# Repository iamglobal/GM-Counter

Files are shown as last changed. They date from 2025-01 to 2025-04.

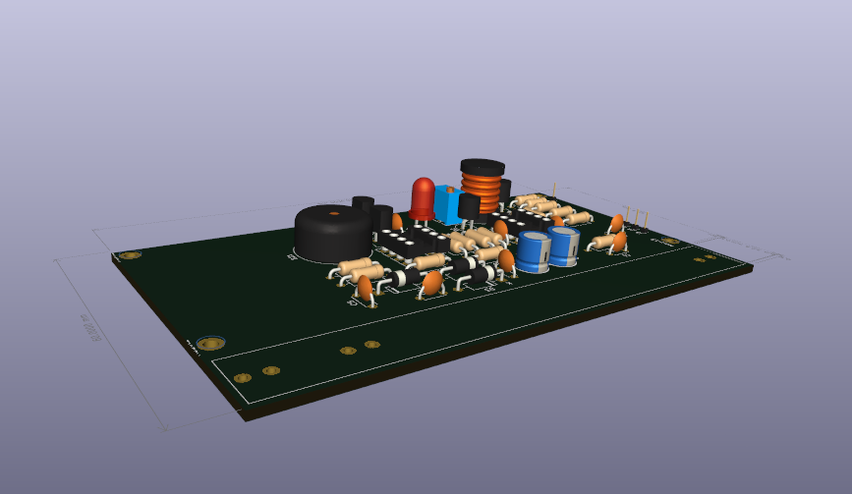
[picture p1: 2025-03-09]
-DOCUMENTATION-/extras/photos of PCB/plosnakv2_3D.png

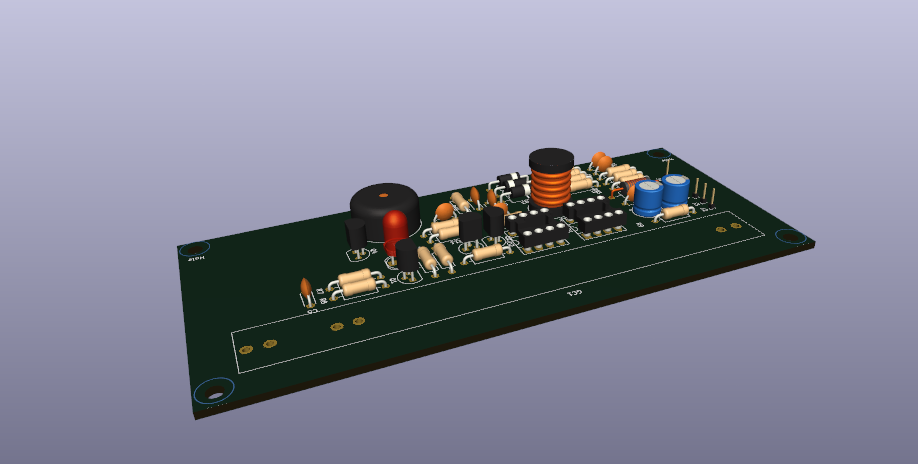
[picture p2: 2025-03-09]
-DOCUMENTATION-/extras/photos of PCB/plosnakv1_3D.png

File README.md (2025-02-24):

# GM-Counter
This is my first project of my own. GM-Counter is a long-term pre-graduation project for SPŠ na Proseku for the year 2025.

## Sources: 
- [SBM-20 data](https://www.gstube.com/data/2398/)
- [GM tubes comparison](https://iot-devices.com.ua/en/comparison-of-geiger-muller-tubes-sbm20-j305-and-lnd712/)
- [GM counter project](https://hackaday.io/project/183103-ggreg20v3-ionizing-radiation-detector)
- [Twin tube GM counter project](https://www.giangrandi.org/electronics/twin-tube-geiger/twin-tube-geiger.shtml)
- [GM Tubes info - CPM to uSv etc.](https://sites.google.com/site/diygeigercounter/technical/gm-tubes-supported)

## Components: 
- [GM kit with M4011 tube (first testing etc.)](https://www.aliexpress.com/item/1005005983829775.html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)
- [SBM-20 GM tube](https://www.ebay.com/itm/280865770387)
- [GM TUBE HOLDER PART](https://cz.mouser.com/ProductDetail/Littelfuse/01020071Z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)
- Arduino Nano
- 0,96 inch OLED display

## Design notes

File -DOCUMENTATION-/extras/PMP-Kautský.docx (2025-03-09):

# Název: Digitální dozimetr

## Popis

Chci vytvořit zařízení, které dokáže měřit ionizující záření. Při naměření radiace „zabzučí“ bzučák a zároveň se rozsvítí LED. Tento pulz se téže dostane do Arduina, do digitálního vstupu (stačí tyto impulzy číst jako 1 a 0). Pro přesnější informaci bude použit displej, kde se bude ukazovat přibližná hodnota radiace v okolí (CPS, CPM, uSv/h, mR/h, nebo jiné). Později mohou být přidány další funkce právě na tento displej (např. Radiace za čas). Je zde i možnost přidání tlačítek k lepšímu ovládání Arduina, např. pro výměnu trubek (každá má jiný převod).

## Řešení

Základem je využít Geigerovu trubici, Arduino a libovolný displej. Geigerova trubice slouží pro měření radiačního záření. Arduino a displej poslouží pro zpracování dat z měření, výpočty a jasné vyhodnocení na zmíněný displej. Celý měřič bude uložen do kompaktního boxu, který nejspíše bude tištěn pomocí 3D tisku. Pro testy trubic a inspiraci jsem si pořídil samotný KIT, který mi bude velkou pomocí. Pro ověření funkčnosti samotného obvodu mám jako zdroj radiace vybrané wolframové elektrody s obsahem Thoria, na kterých zvýšenou radiaci jednoduše naměříme.

## Odkazy

## https://www.instructables.com/Homemade-Geiger-Counter/

https://www.instructables.com/DIY-Arduino-Geiger-Counter/
https://dspace.cvut.cz/bitstream/handle/10467/76812/F8-BP-2018-Kuchar-Libor-thesis.pdf?sequence=-1&isAllowed=y

## Obrázky

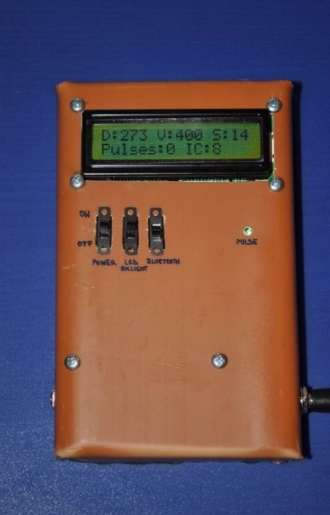
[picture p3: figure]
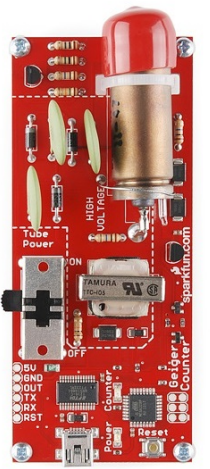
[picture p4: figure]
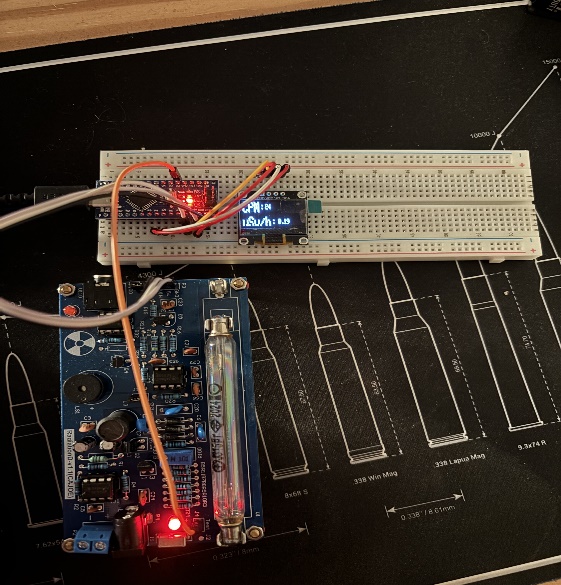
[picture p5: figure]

Příprava dlouhodobé maturitní práce Kautský 3.EA školní rok 2024/2025

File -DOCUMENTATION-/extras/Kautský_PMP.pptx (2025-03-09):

## Digitální dozimetr

PMP 2024/2025

Kautský Ondřej 3.EA

## Úvod

- Výběr projektu: Jako svůj projekt jsem si vybral digitální dozimetr, který slouží k detekci ionizujícího záření. Hlavním senzorem je Geigerova-Müllerova trubice, která reaguje na radioaktivní částice. Celý systém je však řízen vývojovou deskou Arduino. Tento projekt jsem si vybral, protože mě zajímala radiace a její měření.
- Mezi hlavní funkce patří: Vizuální indikace detekovaného záření – pomocí LED Akustická signalizace – zvukový výstup přes buzzer Srozumitelnější data – přepočet impulzů na µSv/h a zobrazení na displeji

## Cíle projektu

Elektrická část – Vyvinout efektivní a funkční PCB, přičemž jsem vycházel z existujícího návrhu a přizpůsobil ho potřebám projektu tím, že jsem odstranil nepotřebné části a jiné zase upravil.
Mechanická část – Navrhnout kompaktní, ale robustní kryt, který bude minimálně ovlivňovat měření.
Programová část – Vytvořit program pro zobrazování vypočtených dat na displeji v zásadě na trubce. Rád bych zde přidal funkci, kde lze typ GM trubky vybrat.

## Schéma obvodu

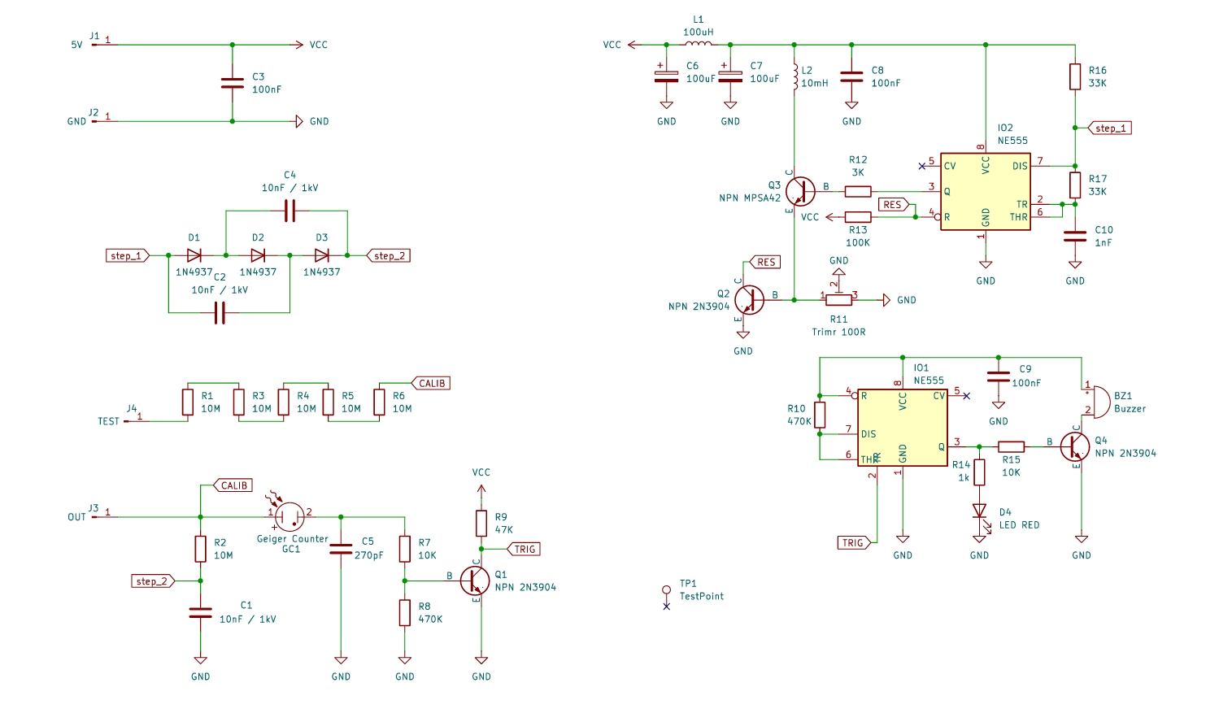
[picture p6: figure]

## Napěťová část (5V -> +-380V)

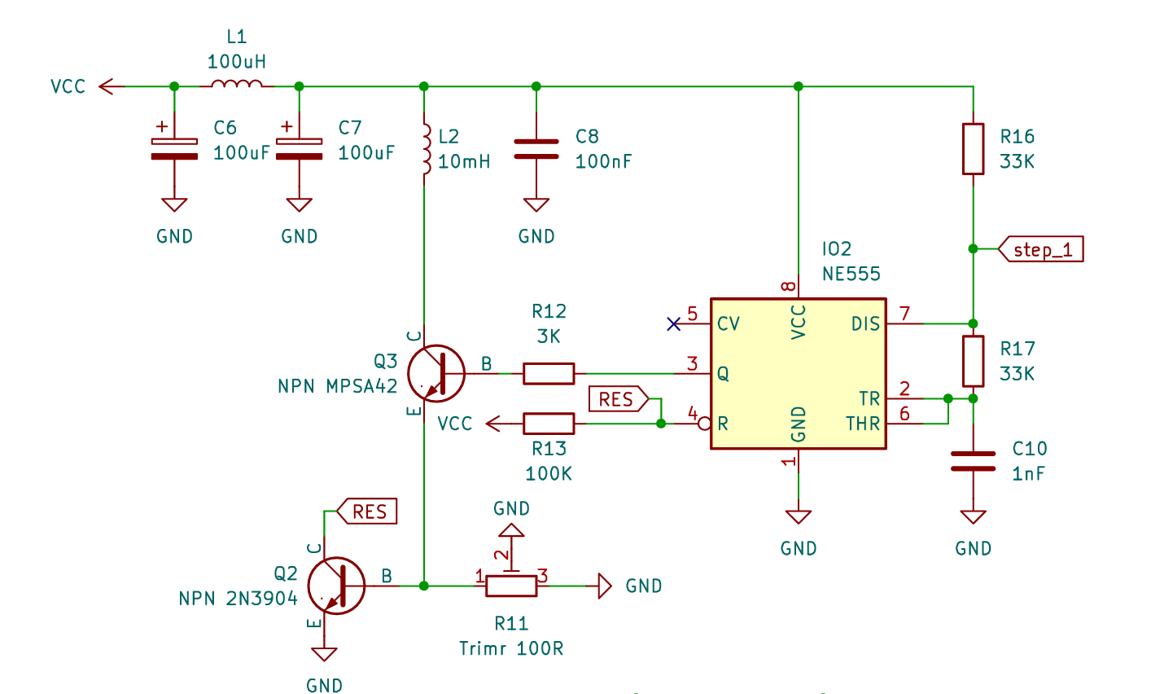
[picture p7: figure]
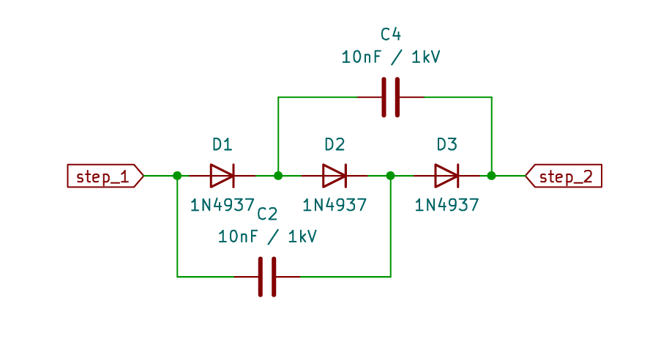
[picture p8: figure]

## Část s vizuální a akustickou signalizací

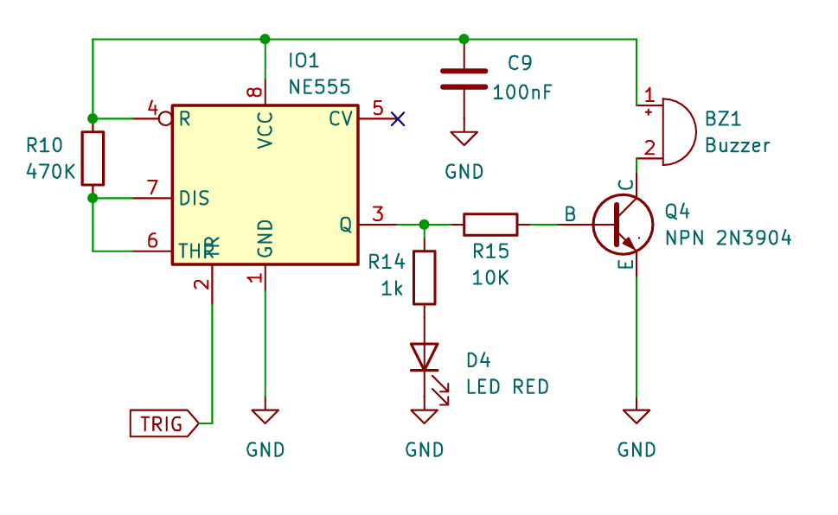
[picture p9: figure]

## Část s GM trubicí

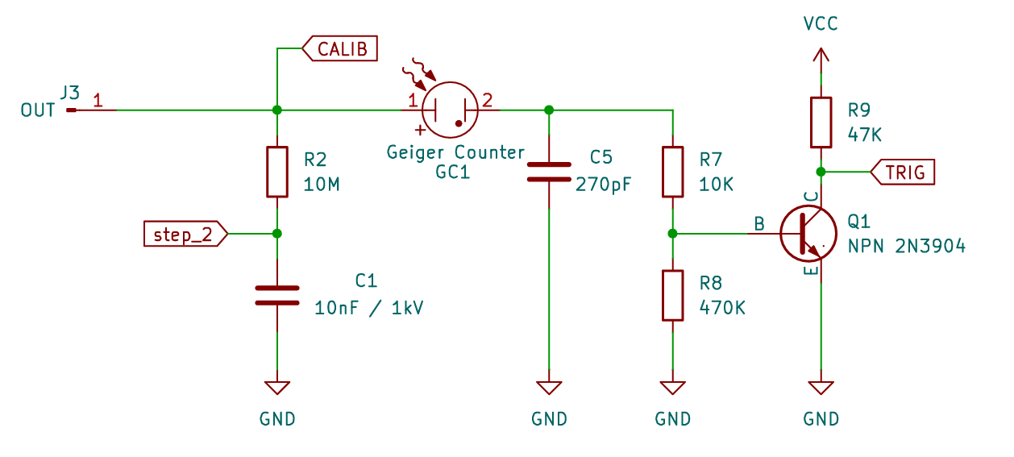
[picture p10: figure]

## PCB v1 (návrh)

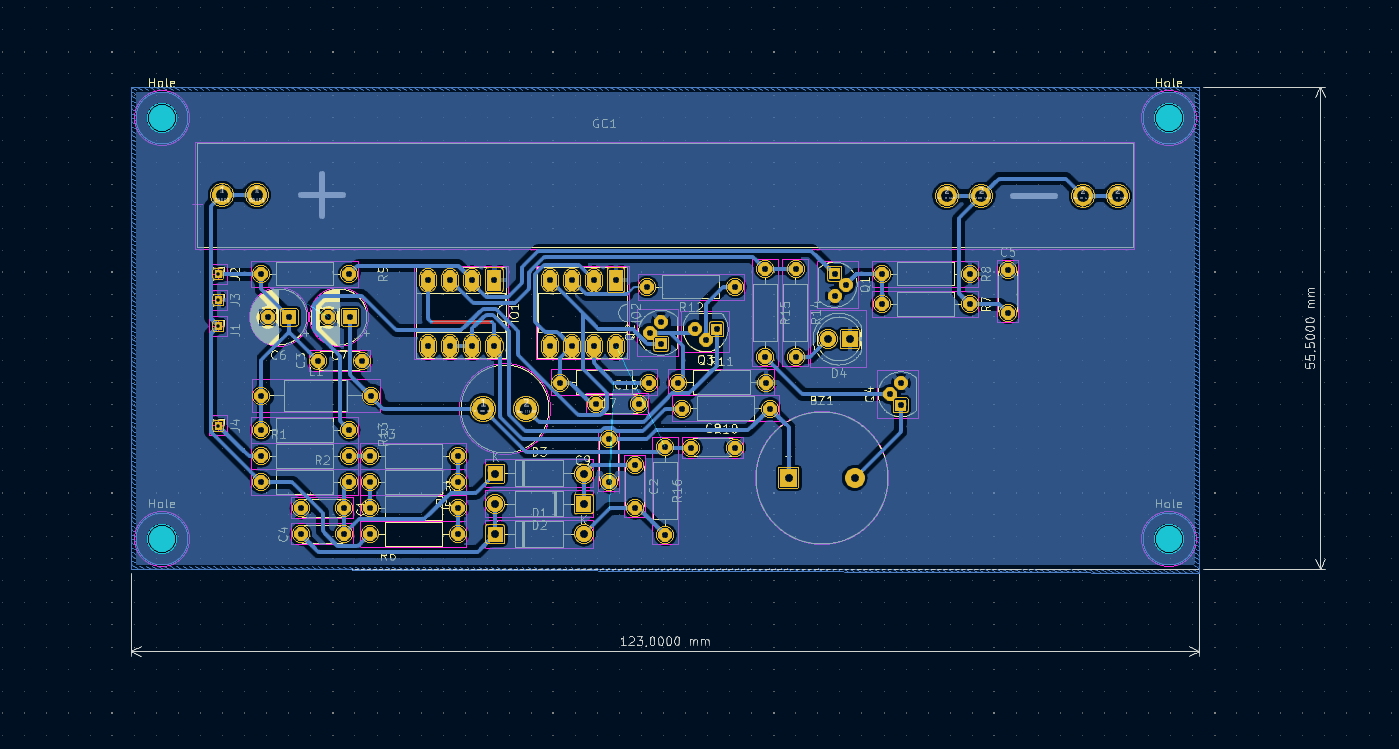
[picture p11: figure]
Obsah obrázku text, snímek obrazovky, mapa, Multimediální software Obsah vygenerovaný umělou inteligencí může být nesprávný.

- Úzké cesty
- Špatné rozvržení
- Relativně velké

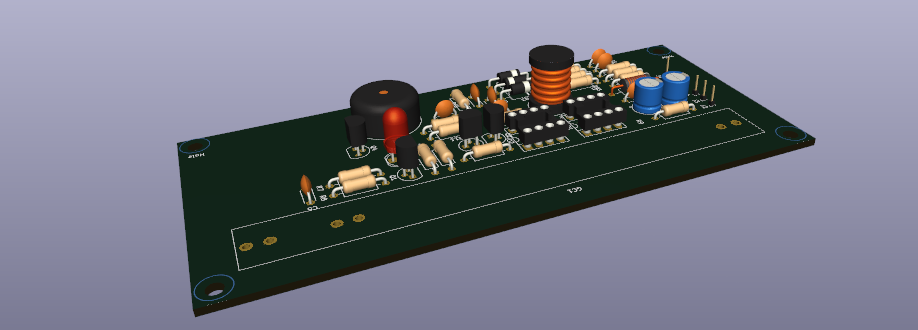
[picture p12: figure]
Obsah obrázku snímek obrazovky, obvod Obsah vygenerovaný umělou inteligencí může být nesprávný.

## PCB v2 (první fyzické)

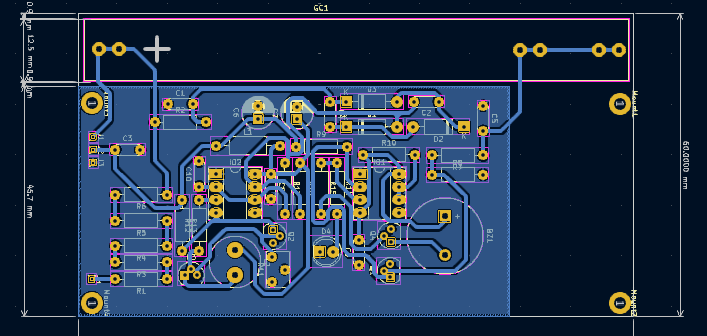
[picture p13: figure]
Obsah obrázku text, mapa, snímek obrazovky, diagram Obsah vygenerovaný umělou inteligencí může být nesprávný.

- Cesty 0,7mm
- Kompaktnější rozměry
- Velké nevyužité místo

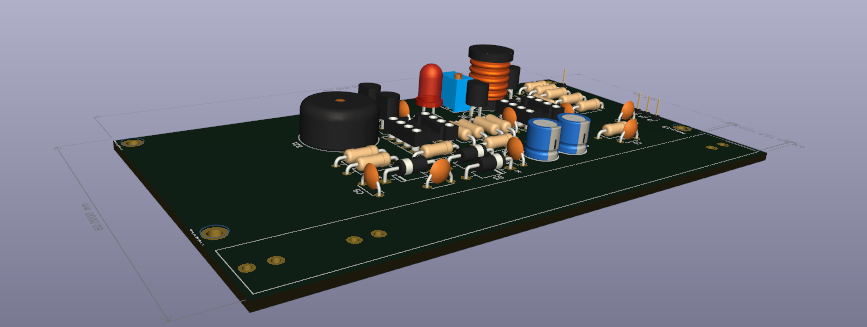
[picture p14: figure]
Obsah obrázku hračka Obsah vygenerovaný umělou inteligencí může být nesprávný.

## PCB v2 – Návrh kompaktního designu

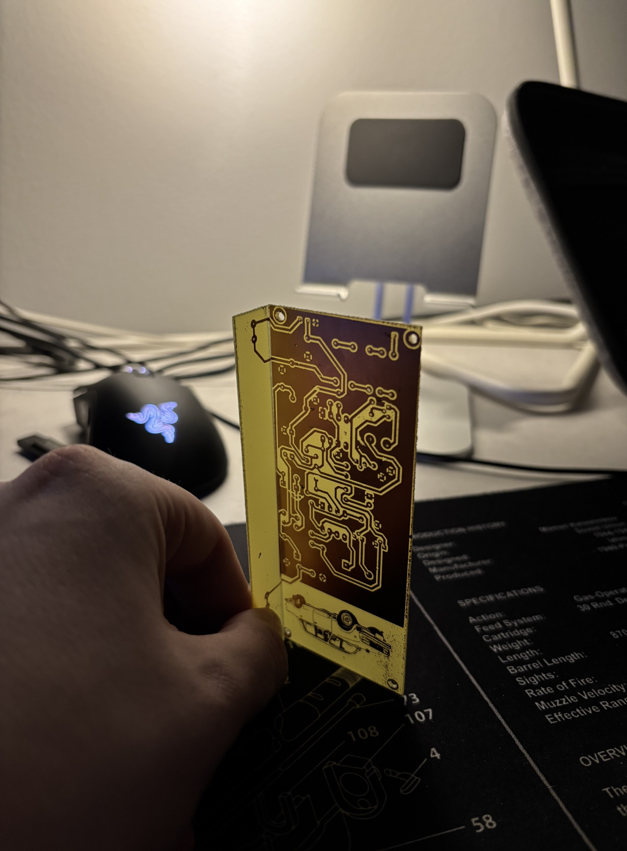
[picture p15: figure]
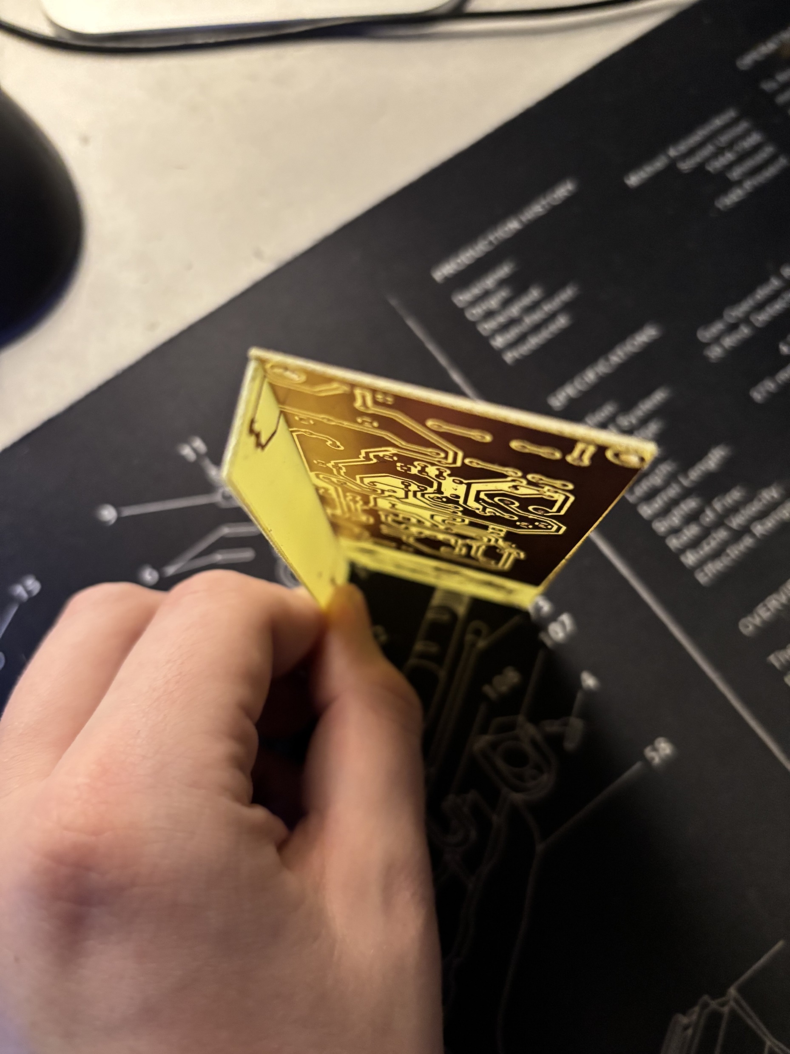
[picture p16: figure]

- Aktuální myšlenka je udělat kompaktní design s jednouchou výměnou GM trubic.
- Tímto designem získám i spoustu místa k umístění baterie pod PCB.
- Nevyužitý prostor na PCB by byl využit pro umístění Arduina a displeje.

První kreslený návrh

## PCB v2 – Fyzická podoba

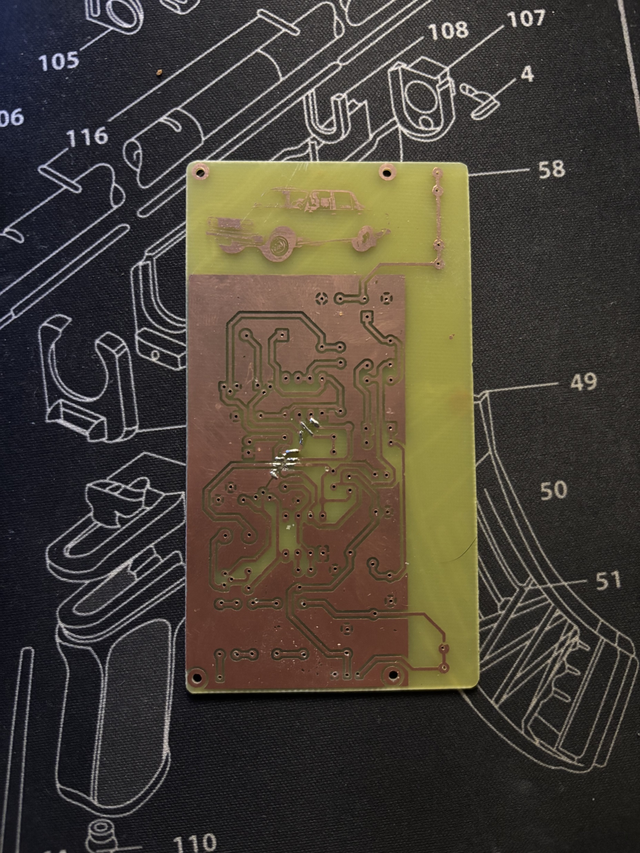
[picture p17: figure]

- K návrhu PCB v2 byly zatím vytvořené 2 kusy. Bohužel se ani jeden nepovedl dostatečně, aby mohl být užit pro první vlastní prototyp. Došlo zde k chybám při leptání (přerušení cest, špatné díry apod.)
- Součástky mám všechny, krom jedné, připravené a pouze musím vytvořit dobré a použitelné DPS.
- U designu s zakřivením do 90° musím vyřešit pevnost a samotný kontakt. Nyní zvažuji že na druhý prototyp bych použil konektory.

## PCB v2 Návrh prototypu krabičky

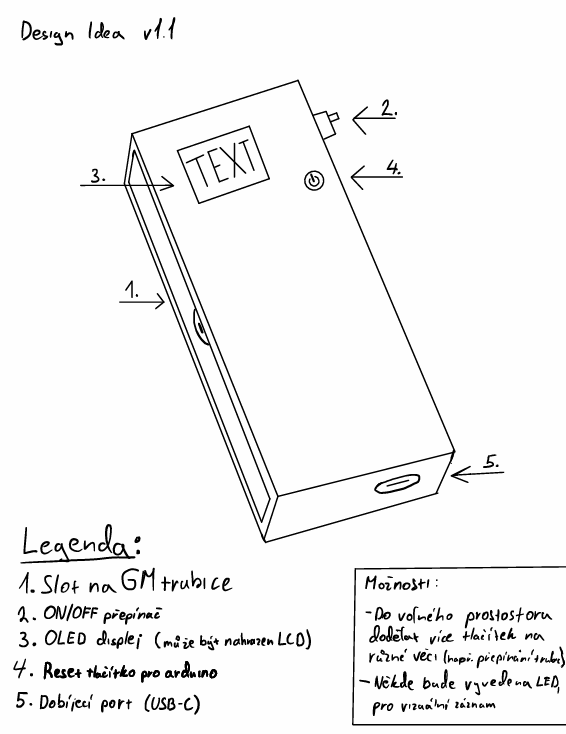
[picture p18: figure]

- Systém otevíracího slotu pro výměnu GM trubic
- Baterie pod DPS
- Velké nevyužité místo (prozatím)

## Cíle do konce dubna

- Dokončit a vytvořit funkční PCB v2
- Vyřešit zbytek programové části (alespoň pro PCB v2)
- Vytisknout, či jinak vytvořit krabičku
- Vyřešit pevnost u designu 90° ohybu
- Zprovoznit zapojení na baterii a její dobíjení

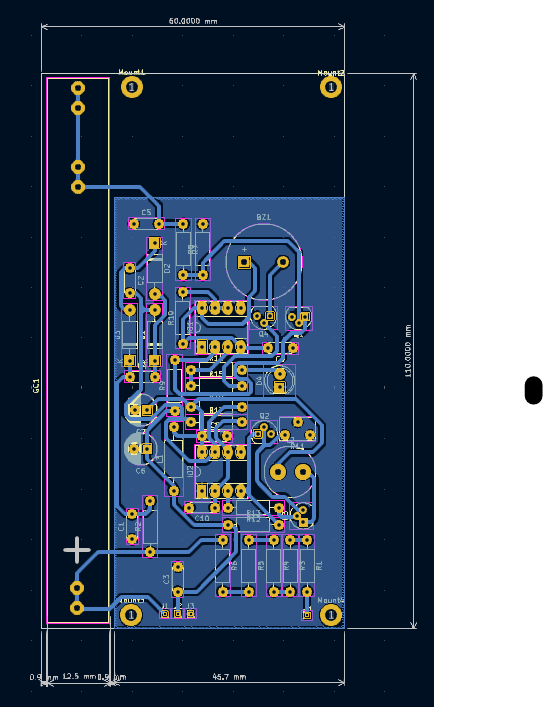
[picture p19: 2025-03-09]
-DOCUMENTATION-/extras/photos of PCB/plosnakv2.png

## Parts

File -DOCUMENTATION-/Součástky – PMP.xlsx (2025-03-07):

 | soucastky na V1 - 1 pokus. Vzit aspon 3x times.
 | Součástka | Počet | URL / KOD | cena
1. | Buzzer | 1ks |  |  | knop
2. | C 10n/1kV | 3ks | CC1K-10N | GM | mam
3. | C 100nF | 5ks | JFH-100N |  | mam
4. | C 270pF | 1ks | CC-271/500 |  | mam
5. | C 1nF | 1ks | CC-1N | GM | mam
6. | D 1N4937 | 3ks | 1N4937-DC |  | mam
7. | LED | 1ks | LTL-4221N |  | mam
8. | NE555 | 2ks | NE555P |  | mam
9. | pin header lista | 1ks | ZL201-40G | GM | mam
10. | L1 100uH R like | 1ks | DLA100-N |  | mam
11. | L2 10mH C like | 1ks | COIL1010-10 |  | mam
12. | NPN 3904 | 3ks | 2N3904-DIO |  | mam
13. | NPN MPSA42 | 1ks | MPSA42-DIO |  | mam
14. | R 10M | 7ks | 1/4W1.0M |  | mam
15. | R 470K | 2ks | 1/4W470K | GM | mam
16. | R 47K | 1Ks | 1/4W47K | GM | mam
17. | R 100K | 1ks | 1/4W100K | GM | mam
18. | R 3K nebo něco close | 2ks | 1/4W3.3K | GM | mam
19. | R 10K | 2ks | 1/4W10K | GM | mam
20. | R 33K | 2ks | MF0207FTE-33K | GM | mam | 2x
21. | TRIMR 100R | 1ks | T910Y-100R
22. | pad na N555 | 2ks | ICVT-8P |  | mam | 2x
23. | drzak na pojistky | 3ks | 01000056Z |  | mam
24. | R 1K | 1ks | 1/4W1.0K | GM | mam
25.
26.
27.
28.
29.
30.

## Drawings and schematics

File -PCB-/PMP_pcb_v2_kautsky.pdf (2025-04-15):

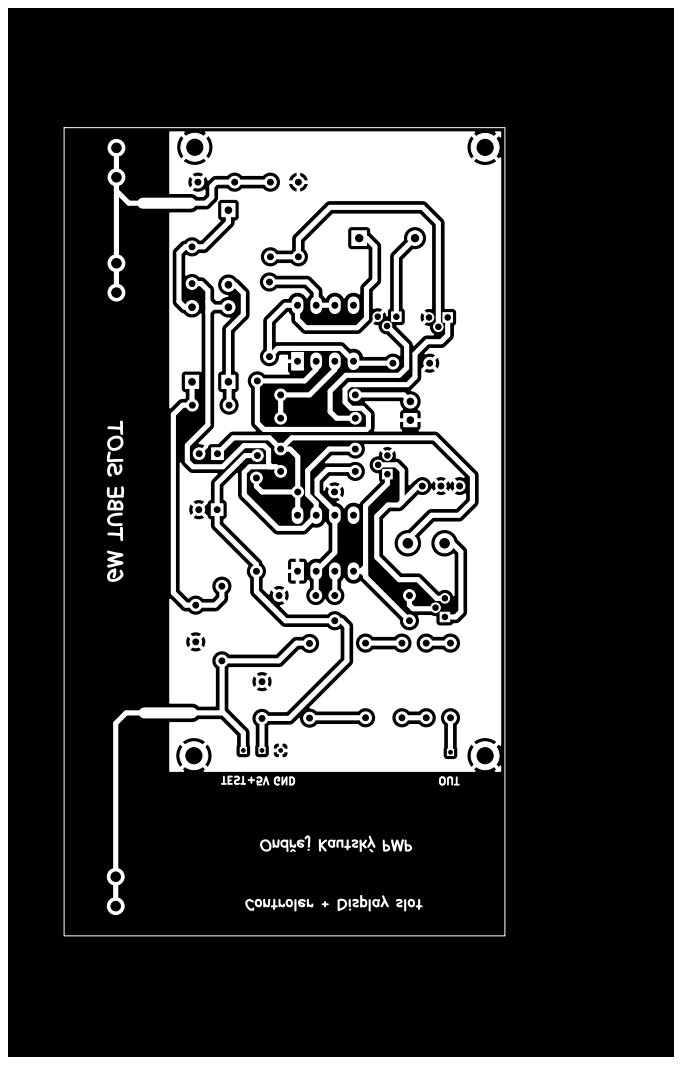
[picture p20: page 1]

+5V GND GM TUBE SLOT

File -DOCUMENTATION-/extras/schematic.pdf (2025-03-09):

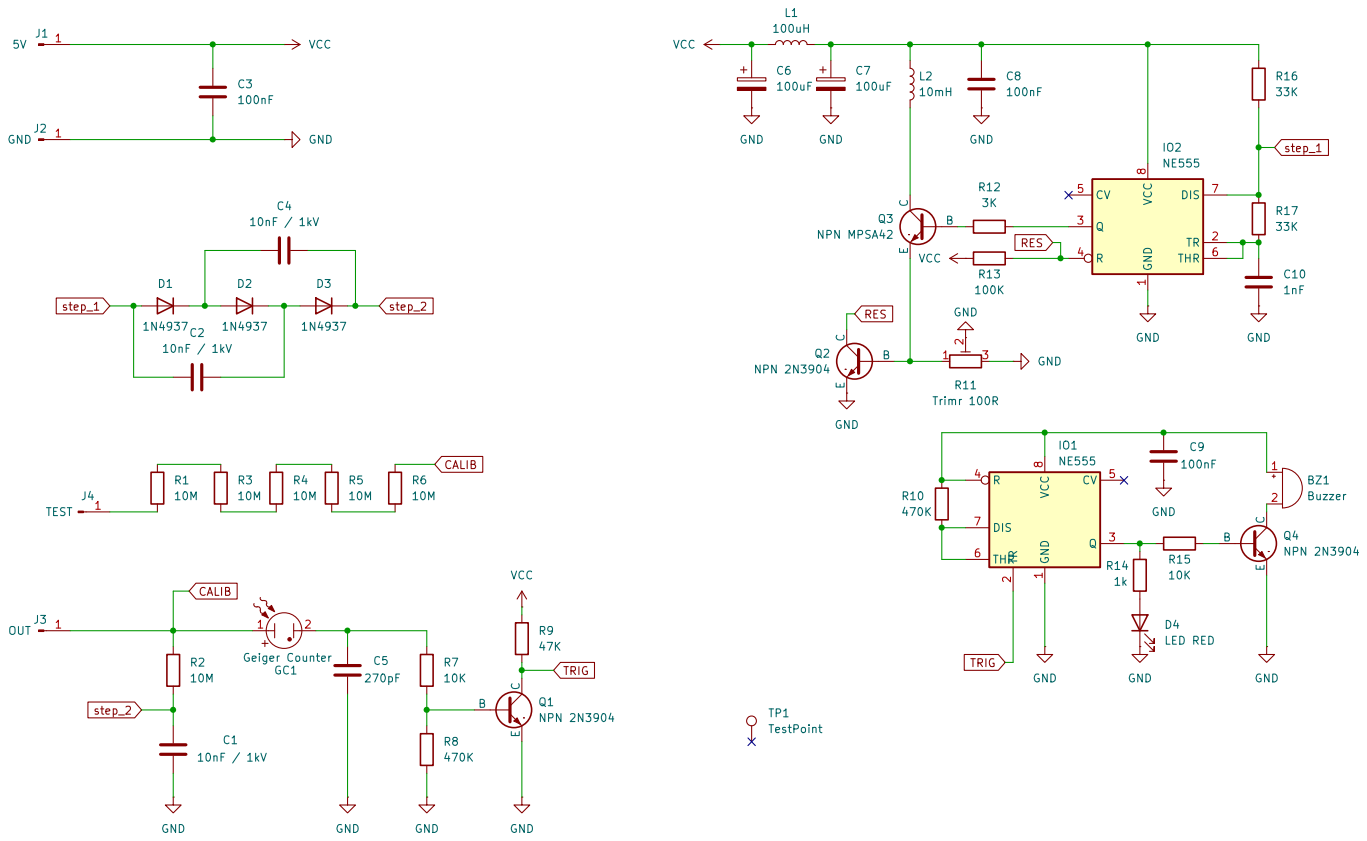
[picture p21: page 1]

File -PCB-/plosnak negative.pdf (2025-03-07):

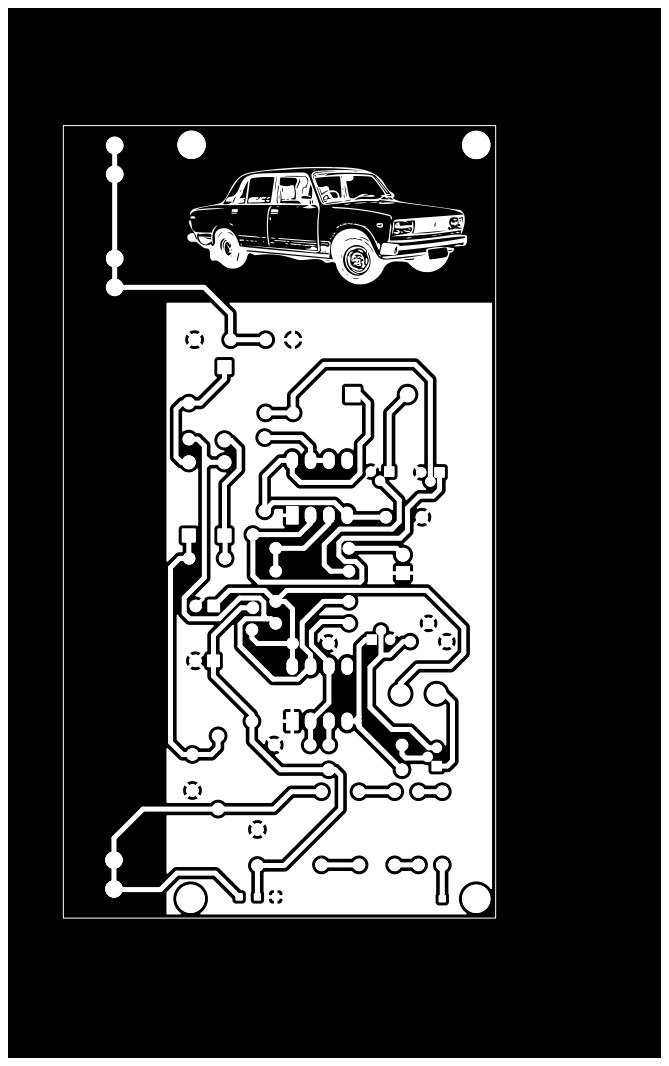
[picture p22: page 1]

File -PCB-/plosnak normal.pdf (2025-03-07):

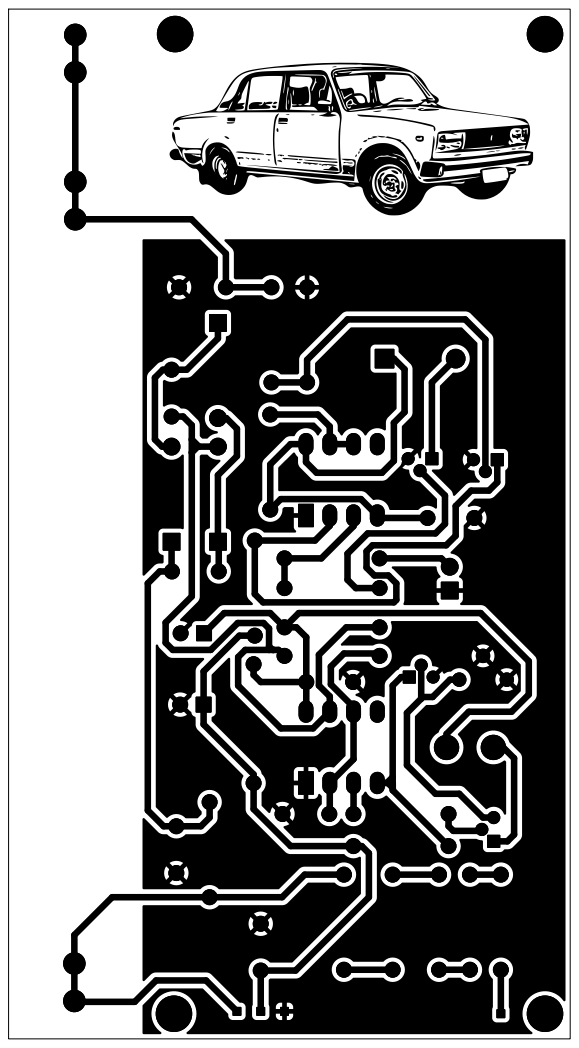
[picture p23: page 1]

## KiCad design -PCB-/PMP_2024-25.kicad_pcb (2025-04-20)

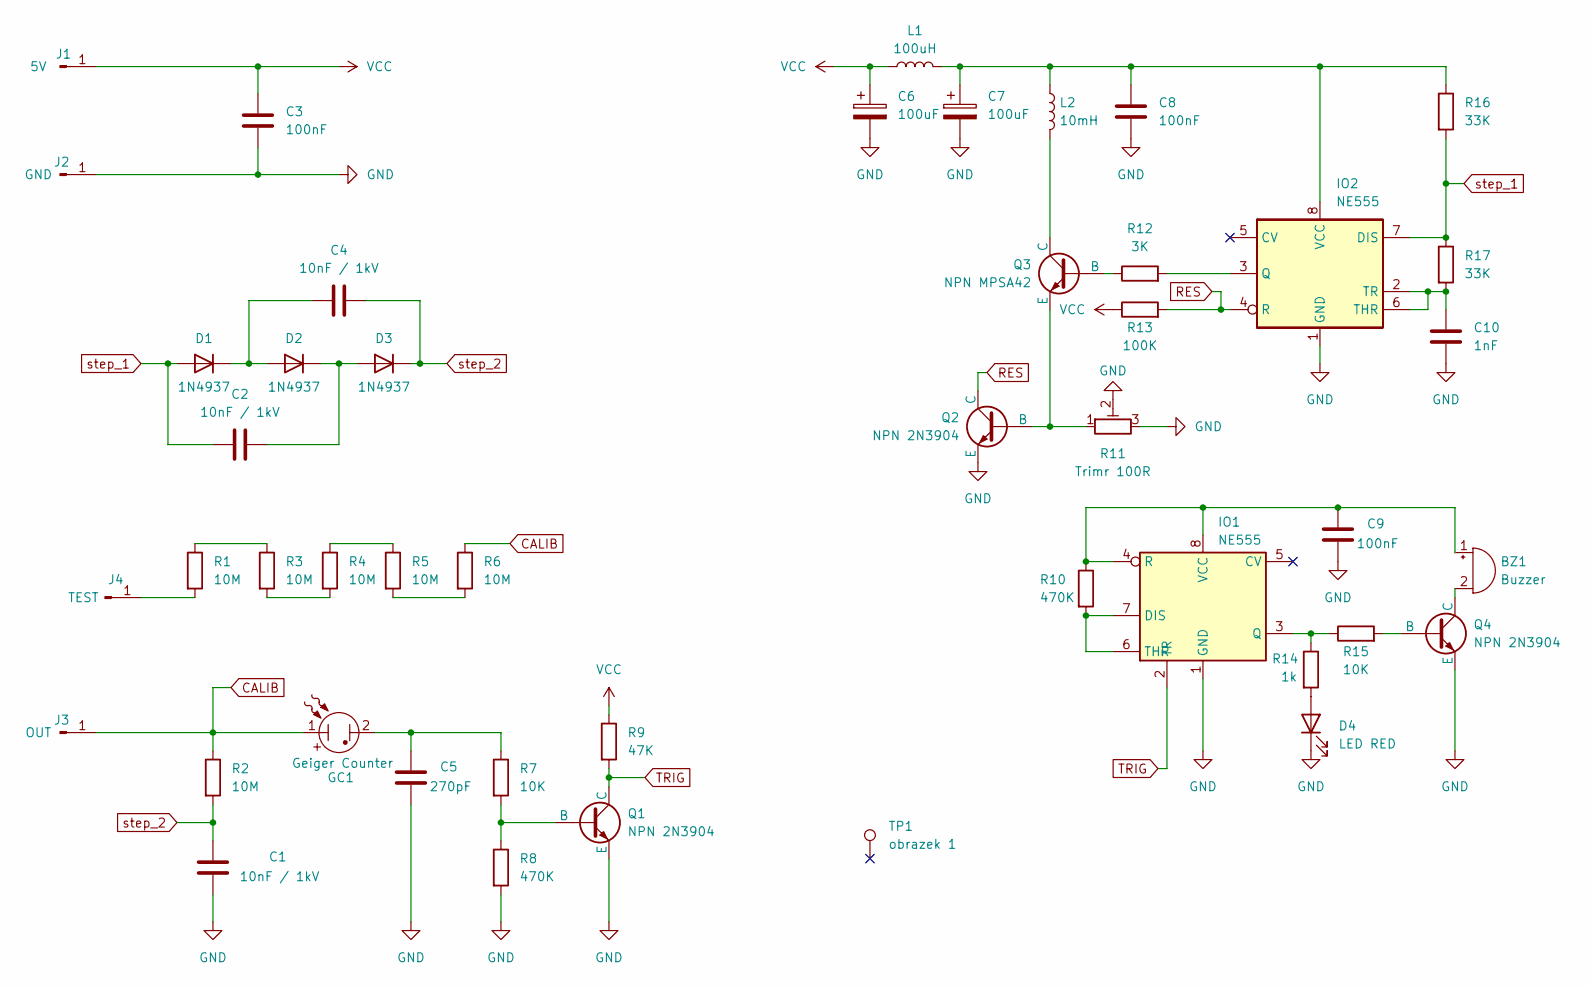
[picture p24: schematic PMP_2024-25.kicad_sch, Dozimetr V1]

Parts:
BZ1: Buzzer; Buzzer_15x7.5RM7.6
C1, C2, C4: 10nF / 1kV; C_Disc_D4.3mm_W1.9mm_P5.00mm
C3, C8, C9: 100nF; C_Disc_D4.3mm_W1.9mm_P5.00mm
C5: 270pF; C_Disc_D4.3mm_W1.9mm_P5.00mm
C6, C7: 100uF; CP_Radial_D6.3mm_P2.50mm
C10: 1nF; C_Disc_D4.3mm_W1.9mm_P5.00mm
D1, D2, D3: 1N4937; D_A-405_P10.16mm_Horizontal
D4: LED RED; LED_D5.0mm
GC1: Geiger Counter; GeigerTube Holder v3 (final)
IO1, IO2: NE555; DIP-8_W7.62mm_Socket_LongPads
J1: 5V; PinHeader_1x01_P1.00mm_Vertical
J2: GND; PinHeader_1x01_P1.00mm_Vertical
J3: OUT; PinHeader_1x01_P1.00mm_Vertical
J4: TEST; PinHeader_1x01_P1.00mm_Vertical
L1: 100uH; L_Axial_L7.0mm_D3.3mm_P12.70mm_Horizontal_Fastron_MICC
L2: 10mH; L_Radial_D10.0mm_P5.00mm_Fastron_07M
Q1, Q2, Q4: NPN 2N3904; TO-92
Q3: NPN MPSA42; TO-92
R1, R2, R3, R4, R5, R6: 10M; R_Axial_DIN0207_L6.3mm_D2.5mm_P10.16mm_Horizontal
R7, R15: 10K; R_Axial_DIN0207_L6.3mm_D2.5mm_P10.16mm_Horizontal
R8, R10: 470K; R_Axial_DIN0207_L6.3mm_D2.5mm_P10.16mm_Horizontal
R9: 47K; R_Axial_DIN0207_L6.3mm_D2.5mm_P10.16mm_Horizontal
R11: Trimr 100R; Potentiometer_Bourns_3296W_Vertical
R12: 3K; R_Axial_DIN0207_L6.3mm_D2.5mm_P10.16mm_Horizontal
R13: 100K; R_Axial_DIN0207_L6.3mm_D2.5mm_P10.16mm_Horizontal
R14: 1k; R_Axial_DIN0207_L6.3mm_D2.5mm_P10.16mm_Horizontal
R16, R17: 33K; R_Axial_DIN0207_L6.3mm_D2.5mm_P10.16mm_Horizontal
TP1: obrazek 1; obrazek1

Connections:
CALIB: GC1.1, J3.1, R2.1, R6.1
GND: C1.1, C3.2, C5.1, C6.2, C7.2, C8.2, C9.1, C10.2, D4.1 (K), IO1.1 (GND), IO2.1 (GND), J2.1, Q1.3 (E), Q2.3 (E), Q4.3 (E), R8.2, R11.2, R11.3; also elsewhere on the board
unnamed: BZ1.1 (+), C9.2, IO1.4 (R), IO1.8 (VCC), R10.1
unnamed: BZ1.2 (-), Q4.1 (C)
unnamed: C5.2, GC1.2, R7.1
unnamed: C4.2, D1.1 (K), D2.2 (A)
unnamed: C2.1, D2.1 (K), D3.2 (A)
unnamed: D4.2 (A), R14.2
unnamed: IO1.6 (THR), IO1.7 (DIS), R10.2
unnamed: IO1.3 (Q), R14.1, R15.1
unnamed: IO2.3 (Q), R12.2
unnamed: C10.1, IO2.2 (TR), IO2.6 (THR), R17.2
unnamed: C7.1, C8.1, IO2.8 (VCC), L1.2, L2.1, R16.1
unnamed: J4.1, R1.2
unnamed: Q1.2 (B), R7.2, R8.1
unnamed: Q2.2 (B), Q3.3 (E), R11.1
unnamed: Q3.2 (B), R12.1
unnamed: L2.2, Q3.1 (C)
unnamed: Q4.2 (B), R15.2
unnamed: R1.1, R3.1
unnamed: R3.2, R4.2
unnamed: R4.1, R5.1
unnamed: R5.2, R6.2
RES: IO2.4 (R), Q2.1 (C), R13.2
TRIG: IO1.2 (TR), Q1.1 (C), R9.2
VCC: C3.1, C6.1, J1.1, L1.1, R9.1, R13.1
step_1: C2.2, D1.2 (A), IO2.7 (DIS), R16.2, R17.1
step_2: C1.2, C4.1, D3.1 (K), R2.2

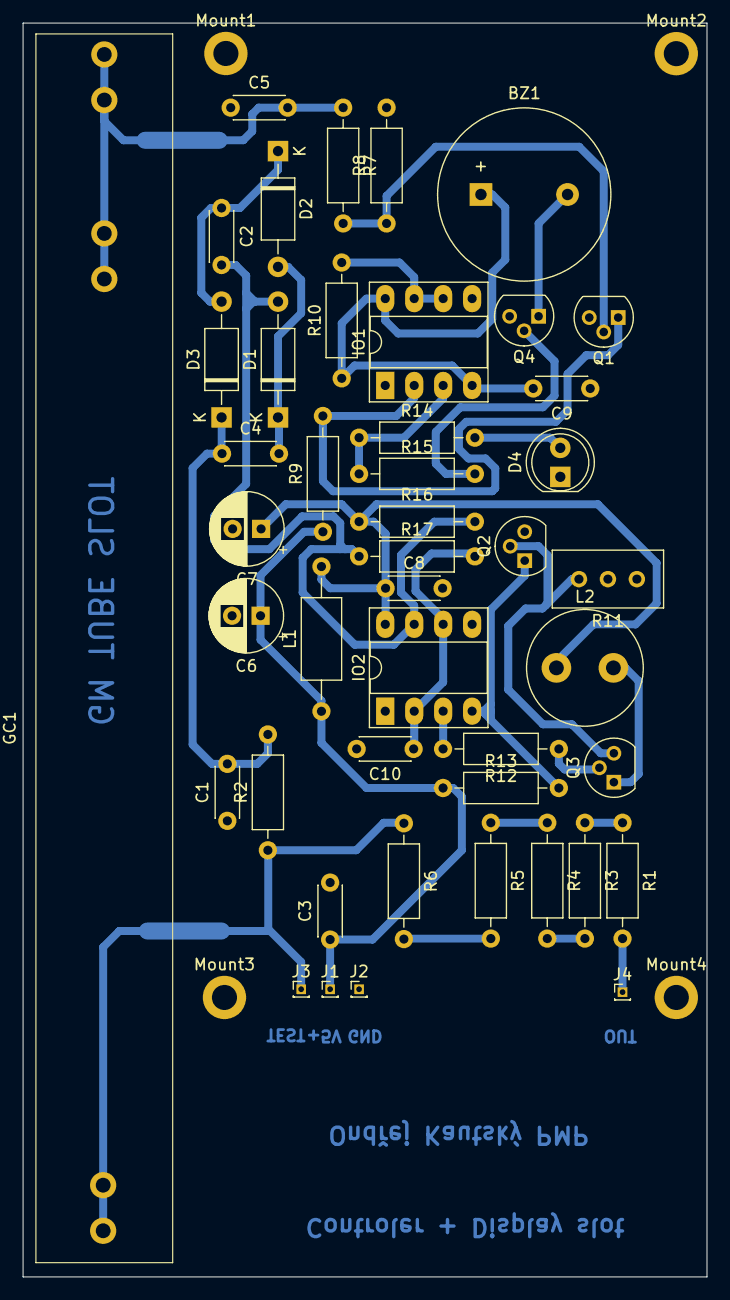
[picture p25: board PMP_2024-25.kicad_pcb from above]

Board: 2 copper layers, 60.0 x 110.0 mm, 50 parts (1 on the bottom side), 28 nets.

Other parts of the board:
Mount1, Mount2, Mount3, Mount4: MountingHole_2.2mm_M2_DIN965_Pad

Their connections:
GND: Mount1.1, Mount2.1, Mount3.1, Mount4.1; also elsewhere on the board

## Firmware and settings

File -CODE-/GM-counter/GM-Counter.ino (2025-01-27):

#include "Arduino_SensorKit.h"

#define GEIGER 2 // Cteni impulzu z obvodu
#define refreshRate 500 
#define pocet_snimani 30

 /* Globalne */
unsigned long pulzy_celkove = 0;
unsigned long pulzy_za_minutu = 0;
int data_pulzu[poccet_snimani];

void setup() {
 /* Nastavení displeje */
  Oled.begin(); 
  Oled.setFlipMode(false); 

 /* Serial */
  Serial.begin(9600);

 /* Pin Modes, Interupty */
  pinMode(GEIGER, INPUT_PULLUP); // musí být pull-up, jinak by nastal floating stav a zaznamenávaly by se falešné pulzy. lze resit tez jako digitalWrite(GEIGER, 1); // pripadne donastavuje pull-up na pinu 2
  attachInterrupt(digitalPinToInterrupt(GEIGER), geiger_pulzy, RISING); // Interupt na cteni pulzu
}
 
void loop() {
/* TESTY */
   





/* ------ */

  unsigned long radiace = analogRead(A0);
  unsigned long cas = millis();
  static unsigned long cas_pred = millis();
  unsigned long cas_prevod = cas / 1000;
  static int radiace_nachytana = 50;
  static int CPM = pulzy_za_minutu;
  

 if((cas - cas_pred) >= refreshRate) { // OLED DISPLAY
    cas_pred = cas;
    Oled.setFont(u8x8_font_chroma48medium8_r);  

    Oled.setCursor(1, 1);    // UI
    Oled.print("---Dozimetr--- ");

    Oled.setCursor(0, 3);   // Radiace aktualne - podle CPM
    Oled.print("Ted: ");
    Oled.print(radiace);   
    Oled.print("uSv/h");

    Oled.setCursor(9, 5);    // CPM (counts per minute)
    Oled.print(CPM); 
    Oled.print("CPM");

    Oled.setCursor(0, 6);    // cas zapnuti 
    Oled.print("Cas: ");
    Oled.print(cas_prevod);
    Oled.print("s");

    Oled.setCursor(0, 7);    // celkova radiace txt
    Oled.print("Celkove: ");
    Oled.print(radiace_nachytana);
    Oled.print("uSv");

    Oled.refreshDisplay();    // refresh displaye
 }


}

void geiger_pulzy() {
  pulzy_celkove++;
  pulzy_za_minutu++;
  Serial.println(pulzy_celkove); // check v serial monitoru
}

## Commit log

2025-01-27 first push
    -
    [PMP_2024-25.kicad_pcb, PMP_2024-25.kicad_sch]
2025-01-27 gitignore test
    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
    [PMP_2024-25.kicad_pcb, PMP_2024-25.kicad_sch]
2025-02-01 Update README.md
    added holder for gm tube
2025-02-24 some edits
    excel added too
    [PMP_2024-25.kicad_pcb, Součástky.xlsx]
2025-02-27 excel added
    [Součástky.xlsx]
2025-02-27 schematic update
    odebrany chyby, pridany krizky apod
    [PMP_2024-25.kicad_sch]
2025-02-27 update excel
    [Součástky.xlsx]
2025-03-01 excel updated
    added codes (TME)
    [Součástky – PMP.xlsx, Součástky.xlsx]
2025-03-01 last update
    soucastky ordered
    [Součástky – PMP.xlsx]
2025-03-07 update exccelll
    added + and -
    [Součástky – PMP.xlsx]
2025-03-07 PCB update
    V2
    [PMP_2024-25.kicad_pcb, PMP_2024-25.kicad_sch]
2025-03-07 more changes
    [PMP_2024-25.kicad_pcb]
2025-03-07 PCB pre-final
    full pcb design V2 - will add picture on the pcb soon
    [PMP_2024-25.kicad_pcb, PMP_2024-25.kicad_sch]
2025-03-07 added image on PCB
    PDF prints added too
    [PMP_2024-25.kicad_pcb, PMP_2024-25.kicad_sch]
2025-03-09 Research from ipad (PDF)
    last update 8.3.
    geiger tubes, first design ideas, some important info
2025-03-09 schematic from kicad
    exported to pdf
2025-03-09 EDITS ON CHEMATIC AND PCB
    renamed pins and changed positions
    [PMP_2024-25.kicad_pcb, PMP_2024-25.kicad_sch]
2025-03-09 DOCS UPDATE
    added pngs of first versions of PCB
    edit in original document about the project
2025-04-15 edits on pcb, design etc.
    box model soon, tommorow creating pcb v2
    [PMP_2024-25.kicad_pcb, PMP_2024-25.kicad_sch]
2025-04-15 text edits
    +export
    [PMP_2024-25.kicad_pcb]
2025-04-20 presentation update
    [PMP_2024-25.kicad_pcb]
